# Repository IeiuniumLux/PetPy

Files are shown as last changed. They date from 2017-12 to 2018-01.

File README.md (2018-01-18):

# PetPy
PetPy is a simple local HTTP server that let you feed your pet remotely. It's built on [MicroPython](http://micropython.org), the lean implementation of the Python 3 standard library that is optimised to run on microcontrollers and in constrained environments. PetPy is simple and hackable enough that can be adapted for other projects or used for testing and learning. It can easly act as a simple interface to receive remote requests to control devices or read analog inputs like the kind used for IOT projects.

## How it works
A food container is attached to a servo and when it turns, a few pellets/kibble/treats drop into the bowl. You can adjust the hole and size of the dispenser depending on whether you are feeding a fish, cat, dog, etc. It serves only one single user connection.

## Authentication
PetPy requires a login first unless the user is detected in the session; which in that case just sends the index.html page. A Cookie is used to store the user session. However, the HttpOnly flag is set so it's not accessible through JavaScript and immune to XSS.

## Behind wifi router
If you want to run PetPy server behind WiFi-router and want it to be accessible from the Internet, then you have to add [port-forwarding](https://www.howtogeek.com/66214/how-to-forward-ports-on-your-router/) rule on your router. This is required in order to forward all of the requests that come to the router within the local network to PetPy server.

## Parts

Below is the list of essential parts you'll need to build the pet feeder.

Part             | Qty 
---------------- | ----
[OpenMV Cam M7](http://openmv.io/products/openmv-cam-m7)<br /> | 1 
[OpenMV Cam WiFi Shield](http://openmv.io/products/wifi-shield "OpenMV Cam WiFi Shield")<br /> | 1 
[OpenMV IR Lens](https://openmv.io/collections/lenses/products/ir-lens "IR Lens")<br /> | 1 
[Clear Acrylic Cement for Bonding Parts](https://www.amazon.com/Glarks-280-Pieces-Phillips-Stainless-Assortment/dp/B01G0KRGXC "Clear Acrylic Cement")<br /> | 1 
[Hitec HS-82MG Metal Gear Micro Servo](https://www.amazon.com/gp/product/B0012YXRJE/ref=ox_sc_act_title_1?smid=A20WEVHROQQX12&psc=1 "HS-82MG Servo")<br /> | 1 
[Barrel Jack to 2-Pin JST Adapter](https://www.frys.com/product/7726848 "Adapter")<br /> | 1 
[3-Inch Diameter Round Tin](https://www.amazon.com/gp/product/B01NCWUE6Y/ref=ox_sc_act_title_1?smid=AZA0I12YMQNES&psc=1 "Round Tin")<br /> *a mini Pringles can should work too* | 1 
[Knurled Thumb Nuts](https://www.ebay.com/itm/321361726270 "Knurled Thumb Nuts")<br /> *optional*| 2 
[4" x 4" Acrylic/Plexiglass Block](https://www.ebay.com/itm/292072330728 "Base")<br /> | 1 
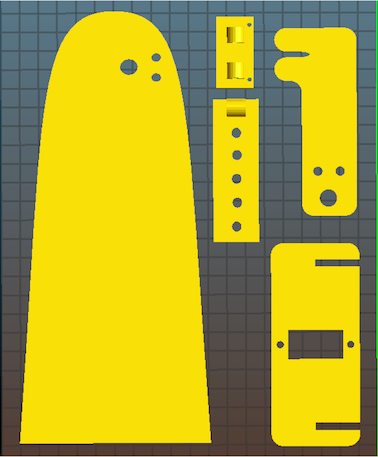
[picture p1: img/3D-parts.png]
Parts
[CAD Parts](stl/ "STL files")<br />*camera mount by Chris Anderson and feeder structure by littleBits* <br /> |

## Resources
[Minifier](http://minifycode.com/html-minifier/ "Minifier")<br />
[CSS Validator](http://jigsaw.w3.org/css-validator/#validate_by_input "Validator")<br />
[Date/Epoch Converter](http://www.esqsoft.com/javascript_examples/date-to-epoch.htm "Converter")<br />
[Router Port Forwarding](https://www.howtogeek.com/66214/how-to-forward-ports-on-your-router/)<br />
[Google Domains](https://domains.google/#/)<br />
[Content Security Policy](https://developers.google.com/web/fundamentals/security/csp/#if_you_absolutely_must_use_it)<br />
[FreeCAD](https://www.freecadweb.org/)<br />

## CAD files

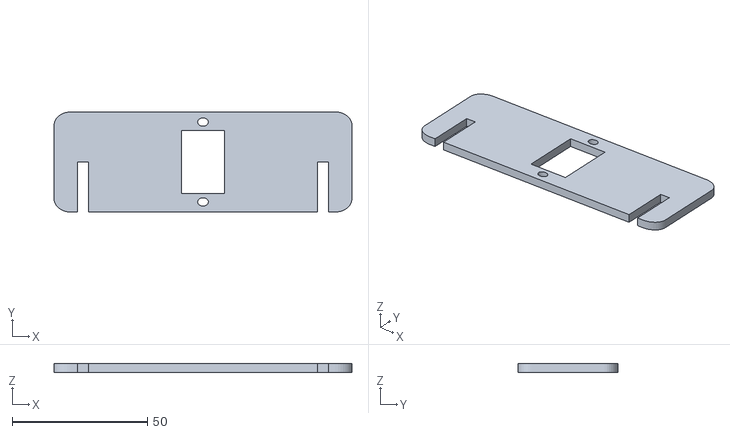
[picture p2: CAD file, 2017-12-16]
stl/tower_servo_holder.stl
110.0 x 37.0 x 3.20

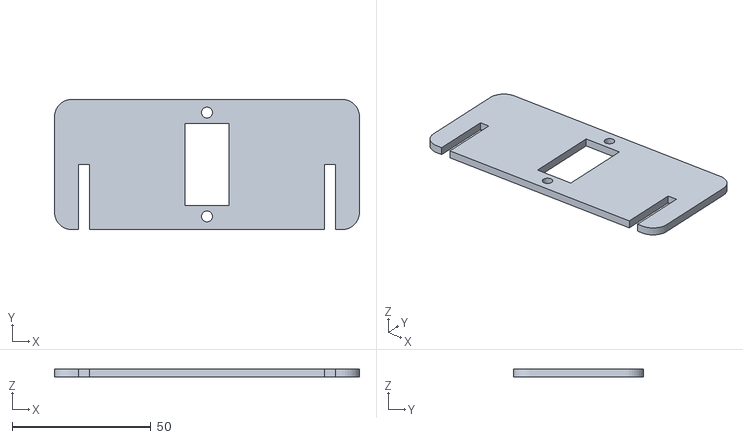
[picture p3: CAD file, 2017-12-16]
stl/hitec_servo_holder.stl
110.0 x 47.0 x 3.00

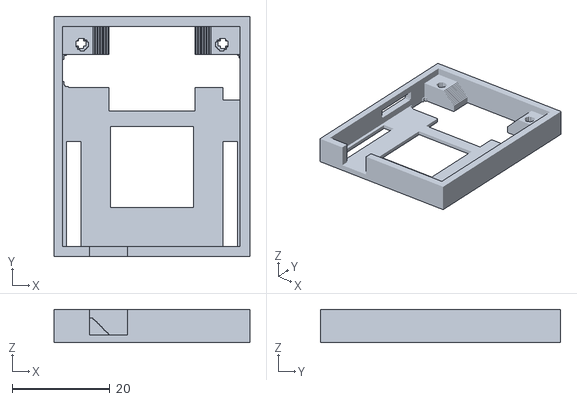
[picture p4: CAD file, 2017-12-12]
stl/openmv_cover.stl
40.0 x 49.0 x 6.75

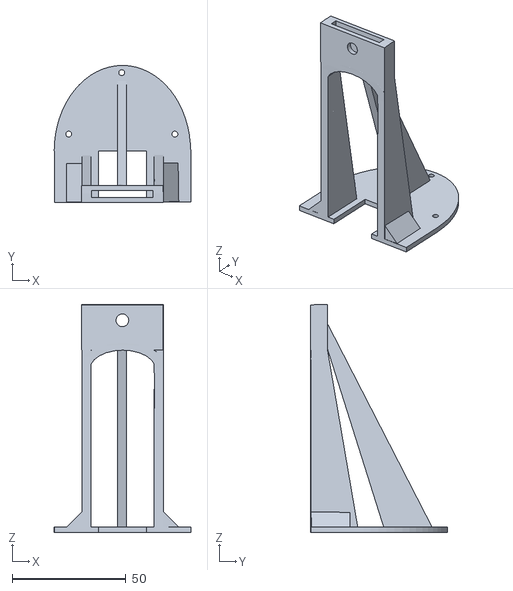
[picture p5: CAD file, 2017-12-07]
stl/openmv_mount0.stl
60.1 x 60.3 x 100.3

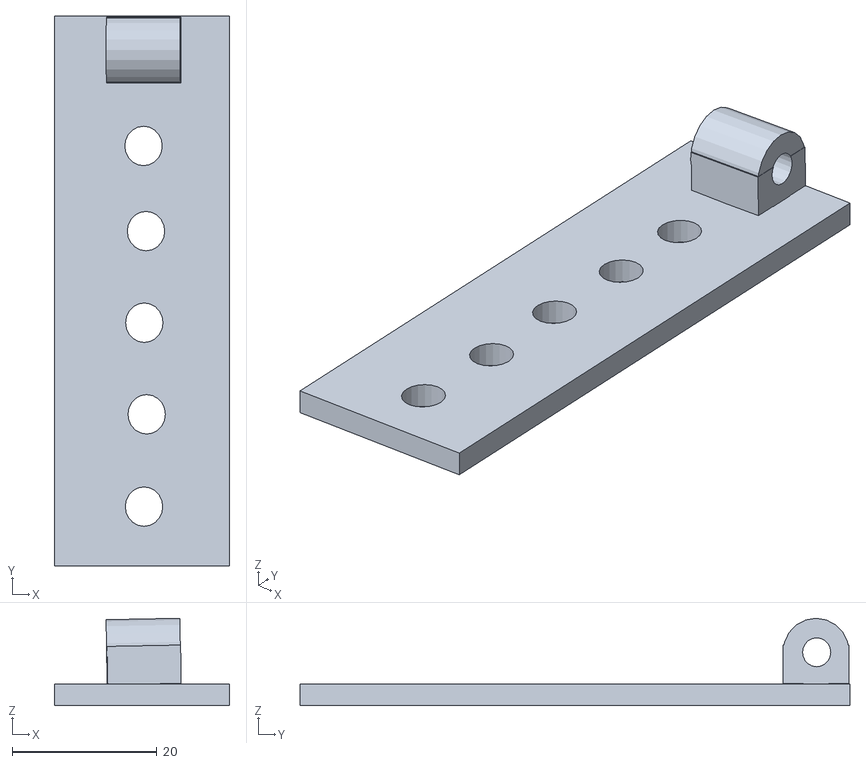
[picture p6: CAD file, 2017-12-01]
stl/openmv_mount1.stl
24.2 x 76.0 x 12.1

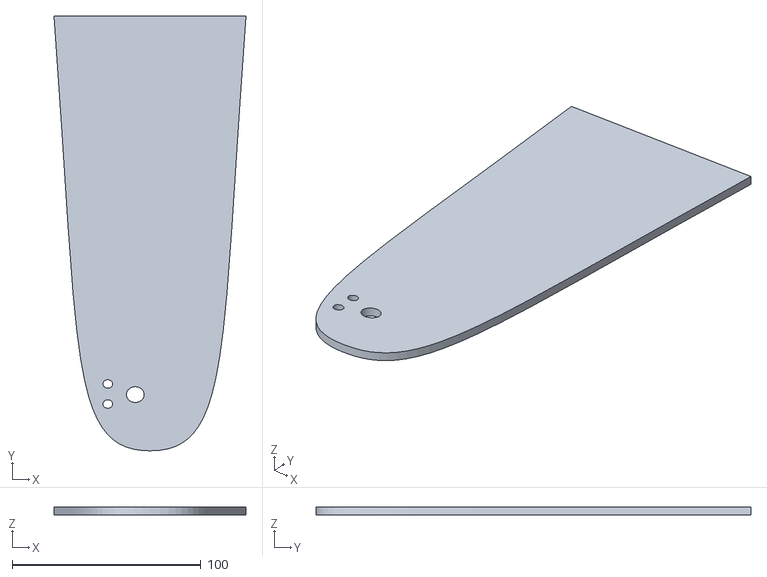
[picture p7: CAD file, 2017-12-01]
stl/side_plate.stl
101.6 x 230.0 x 4.00

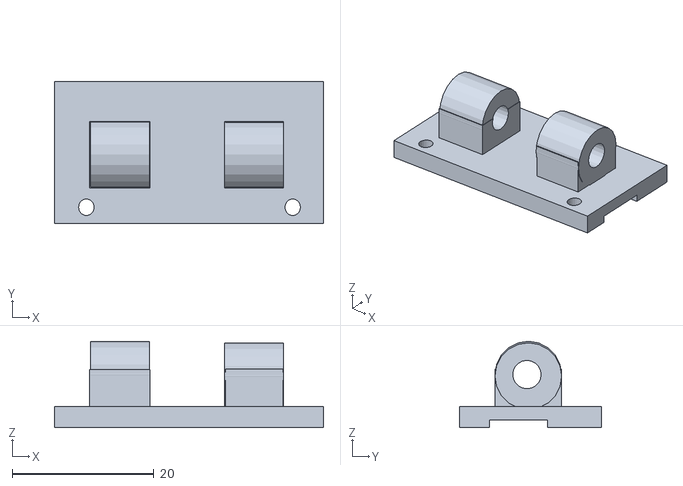
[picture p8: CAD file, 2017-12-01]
stl/openmv_mount2.stl
38.0 x 20.0 x 12.2

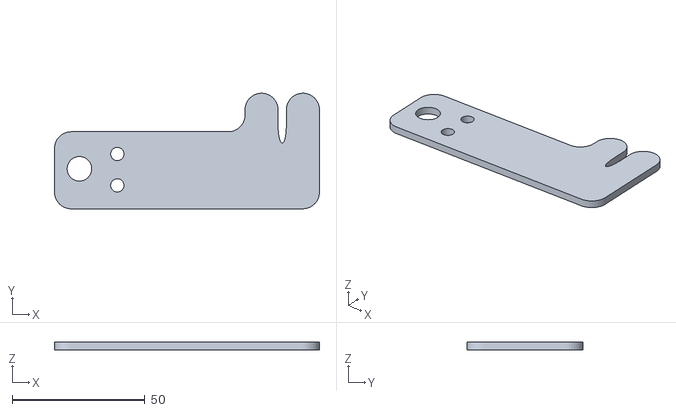
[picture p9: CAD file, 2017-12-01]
stl/shelf_arm.stl
100.0 x 43.6 x 2.86

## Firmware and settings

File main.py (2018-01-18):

# Pet Feeder - By: Al Bee - Sun Nov 28 2017

import gc
import sensor
import network
import usocket
import ure
import utime
import uos
import ubinascii
import uhashlib
from pyb import LED
from pyb import Servo

GREEN_LED = LED(2)
BLUE_LED = LED(3)
servo = Servo(3)  # P9
servo.pulse_width(500)

SSID = 'YOUR_SSID'
KEY =  'YOUR_KEY'
LOG_FILE = 'time.log'
AUTH_FILE = '.htpasswd'
DAY_ABBR = ['Mon', 'Tue', 'Wed', 'Thu', 'Fri', 'Sat', 'Sun']
STATUS = {200:"200 OK", 404:"404 Not Found", 401:"401 Unauthorized", 501:"501 Server Error"}
TURNS = 1

# Set sensor settings
sensor.reset()
sensor.set_framesize(sensor.QQVGA)  # 160x120 resolution
sensor.set_pixformat(sensor.GRAYSCALE)
sensor.skip_frames()

# Init wlan module and connect to 2.4 GHz wifi
wlan = network.WINC()
wlan.connect(SSID, key=KEY, security=wlan.WPA_PSK)


class HTTPServer():

    def __init__(self):
        self.routes = []
        self.session_key = ubinascii.hexlify(uos.urandom(16)).decode("ascii")
        self.debug = False

    @staticmethod
    def build_route_pattern(route):
        return ure.compile('^{}$'.format(route))

    def route(self, route_str):
        def decorator(func):
            route_pattern = self.build_route_pattern(route_str)
            self.routes.append((route_pattern, func))
            return func

        return decorator

    def get_route_match(self, path):
        for route_pattern, route_function in self.routes:
            m = route_pattern.match(path)
            if m:
                if m.group(0) is not None:
                    return dict([("key", m.group(0))]), route_function
                return {}, route_function
        return None

    def run(self, host='', port=8088, debug=False):
        gc.collect()
        self.debug = debug
        server = usocket.socket(usocket.AF_INET, usocket.SOCK_STREAM)
        server.bind([host, port])
        server.listen(1)
        server.settimeout(0)  # Set server socket to non-blocking
        while True:
            try:
                BLUE_LED.off()
                conn, addr = server.accept()
                BLUE_LED.on()
                conn.settimeout(9.0)
                request = conn.recv(1024).decode('utf-8')

                path_info = request.splitlines()[0].split()[1]
                route_match = self.get_route_match(path_info)
                if route_match:
                    kwargs, route_function = route_match
                    route_function(**dict(kwargs, conn=conn, request=request))
                else:
                    if debug:
                        print('Route "{}" has not been registered'.format(path_info))
                    error(conn, STATUS[404], 'Error 404: Page not found')

            except OSError:
                pass
            except:
                BLUE_LED.off()
                conn.close()
                raise

            conn.close()


app = HTTPServer()


@app.route('/')
def index(key, conn, request):
    try:
        if app.debug:
            print(request)

        # headers are split from body by a \r\n\r\n sequence
        (headers, body) = request.split("\r\n\r\n")
        if body:
            password = read_value(AUTH_FILE)
            if body != password:
                error(conn, STATUS[401], 'Authentication failed.')
                return

        elif not hastoken(conn, headers):
            return

        with open('/static/index.html', 'rb') as html:
            send_headers(conn, True)
            last_feed = utime.localtime(int(read_value(LOG_FILE)))
            ptag = '<p id="lastfeed">Last Feed: {} {:d} @ {:02d}:{:02d}</p>'.format( \
            DAY_ABBR[last_feed[6]], last_feed[2], last_feed[3], last_feed[4])
            nonce = ubinascii.hexlify(uos.urandom(16)).decode("ascii")
            conn.send(html.read() % ('\'nonce-{}{}'.format(nonce, '\''), ptag, \
            'nonce={}'.format(nonce)))
    except OSError:
        error(conn, STATUS[404], 'Error 404: Page not found')


@app.route('/(\d+.)')
def stream(key, conn, request):
    # Send multipart header
    conn.send("HTTP/1.1 200 OK\r\n" \
              "content-type: multipart/x-mixed-replace;boundary=stream\r\n" \
              "x-frame-options: deny\r\n" \
              "x-xss-protection: 1; mode=block\r\n" \
              "x-content-type-options: nosniff\r\n" \
              "vary: Accept-Encoding\r\n" \
              "cache-control: no-cache\r\n\r\n")
    frame = sensor.snapshot()
    cframe = frame.compressed(quality=50)
    conn.send("\r\n--stream\r\n" \
               "content-type: image/jpeg\r\n" \
               "content-length:{}\r\n\r\n".format(cframe.size()))
    conn.send(cframe)


@app.route('/feed/(\d+.)')
def feed(key, conn, request):
    (headers, body) = request.split("\r\n\r\n")
    if not hastoken(conn, headers):
        return

    GREEN_LED.on()
    counter = 0
    while counter < TURNS:
        servo.pulse_width(2100)
        utime.sleep_ms(400)
        servo.pulse_width(500)
        counter = counter + 1
    GREEN_LED.off()
    save_value(LOG_FILE, str(key[6:]))
    send_headers(conn)


@app.route('/static/(.+)')
def resource(key, conn, request):
    encoding = 'identity'
    if key.endswith(".js"):
        mimetype = 'application/javascript'
        # encoding = 'gzip'
    elif key.endswith(".css"):
        mimetype = 'text/css'
        #encoding = 'gzip'
    elif key.endswith(".ico"):
        mimetype = 'image/x-icon'
    elif key.endswith(".svg"):
        mimetype = 'image/svg+xml'
    elif key.endswith(".png"):
        mimetype = 'image/png'
    else:
        mimetype = 'text/html'

    #filesize = get_size(key)

    send_headers(conn, False, mimetype, encoding, 'max-age=604800')

    with open(key, 'rb') as f:
        conn.send(f.read())


def error(conn, status, message):
    conn.send("HTTP/1.1 {}\r\n" \
              "content-type: text/html\r\n" \
              "vary: Accept-Encoding\r\n" \
              "cache-control: no-cache\r\n\r\n" \
              "<center><h3>{}</h3></center>".format(status, message))


def hastoken(conn, headers):
    headers = parse_headers(headers)
    if not isset(headers, 'cookie'):
        with open('/static/login.html', 'rb') as html:
            send_headers(conn)
            nonce = ubinascii.hexlify(uos.urandom(16)).decode("ascii")
            conn.send(html.read() % ('\'nonce-{}{}'.format(nonce, '\''), \
            'nonce={}'.format(nonce)))
            return False
    return True


def send_headers(conn, cookie=False, mimetype='text/html', encoding='identity', cache='no-cache'):
    conn.send("HTTP/1.1 200 OK\r\n" \
              "content-type: {0}; charset=UTF-8\r\n" \
              "access-control-allow-origin: *\r\n" \
              "access-control-allow-methods: POST, GET, OPTIONS\r\n" \
              "access-control-allow-headers: Origin\r\n" \
              "x-frame-options: deny\r\n" \
              "x-xss-protection: 1; mode=block\r\n" \
              "x-content-type-options: nosniff\r\n" \
              "content-encoding: {1}\r\n" \
              "vary: Origin\r\n" \
              "cache-control: {2}\r\n{3}".format(mimetype, encoding, cache, \
              "set-cookie: token={}; HttpOnly;\r\n\r\n".format(app.session_key) \
              if cookie else "\r\n"))


def parse_headers(request):
    headers = {}
    for line in request.split('\n')[1:]:
        # blank line separates headers from content
        if line == '\r':
            break
        header_line = line.partition(':')
        headers[header_line[0].lower()] = header_line[2].strip()
    return headers


def isset(headers, key):
    value = None
    if key in headers:
        value = headers[key]
    return value


def get_size(filename):
    info = uos.stat(filename)
    return info[6]


def read_value(filename):
    v = str(0)
    try:
        with open(filename, 'rb') as f:
            v = f.read()
            if not v:
                v = str(0)
    except OSError:
        save_value(filename, v)

    return v.decode('utf-8')


def save_value(filename, value):
    try:
        with open(filename, 'wb') as f:
            f.write(value)
    except OSError as err:
        if app.debug:
            print(err)


def hash_str(string_to_hash):
    hashed = uhashlib.sha256(string_to_hash.encode()).digest()
    encoded = ubinascii.b2a_base64(hashed)
    print(encoded.decode("ascii"))
    return encoded


if __name__ == '__main__':
    app.run(debug=True)

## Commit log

2017-11-05 wsBcBAABCAAQBQJZ/2AiCRBK7hj4Ov3rIwAAdHIIAGg+z5ZIKekpnY59zrdxcUKV edNRwVfeEhByCJ4HXCYgwy2VlVqWdb01MNPjZPnt0qDXGyB0iFjalpMyJPjMhikb XqZJ3h+zdO9DucO2QEcEDdwLkqt7+e3W5/NpaMaRjl1eEm71jw9S5qcof+TER/kP XgCX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
    Initial commit
2017-12-01 intial commit
    [openmv_mount1.stl, openmv_mount2.stl, servo_holder.stl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]
